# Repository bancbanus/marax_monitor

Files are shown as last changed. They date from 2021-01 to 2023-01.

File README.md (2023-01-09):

# marax_monitor
Shows temperature data and pump activity of Lelit's MaraX (PL62X) espresso machine with an ESP8266 on a 3.2" Nextion display
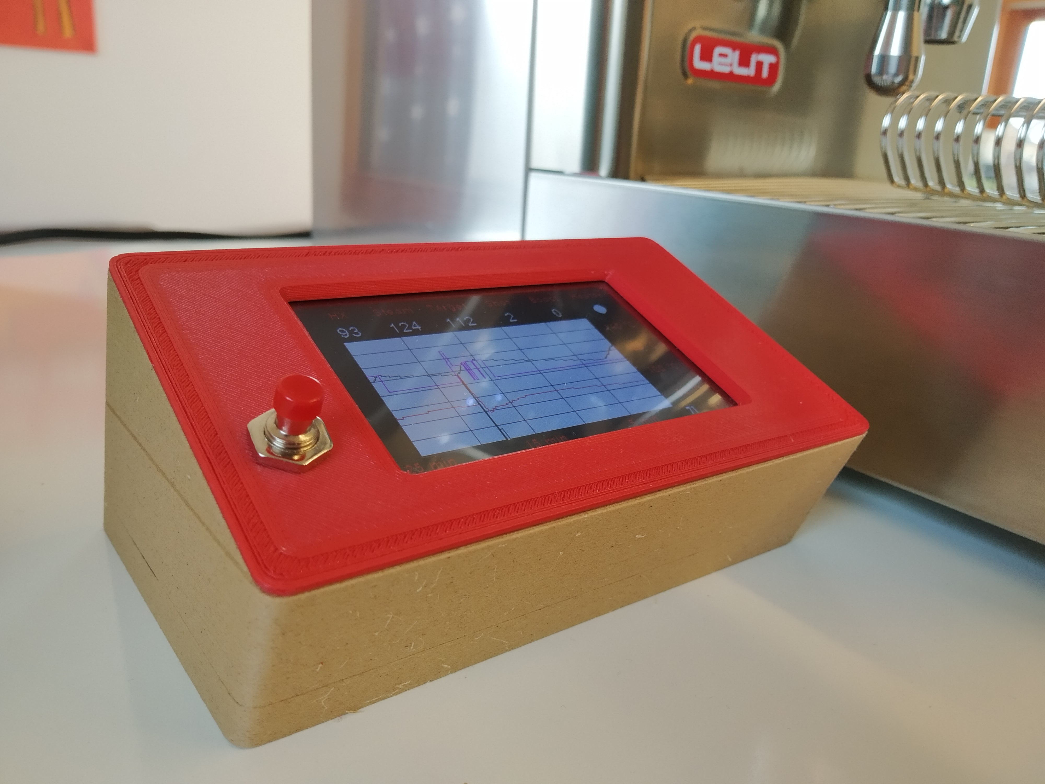
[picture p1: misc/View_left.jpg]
marax_monitor


## Introduction
[Lelit's MaraX (PL62X)](https://marax.lelit.com/) espresso machine is a quite interesting device because of it's "coffee mode", i.e. 
temperature is regulated by measuring the HX temperature instead of the steam temperature. The control unit of the machine provides 
a serial interface which allows us to read all relevant data.

There are already many projects out there which read and display the machine's data, but I want to draw your attention to following 
two projects from where I got a lot of ideas and information (thank you!):

* [calin's excellent post on reddit](https://www.reddit.com/r/espresso/comments/hft5zv/data_visualisation_lelit_marax_mod/)
* [alexrus' great marax_timer project](https://github.com/alexrus/marax_timer)
* [lelit insider's video](https://youtu.be/9NL6yeq7sMM)

Since a Nextion display was laying around in my lab, I created marax_monitor which does the following:

* Display and plot temperatures on a Nextion display
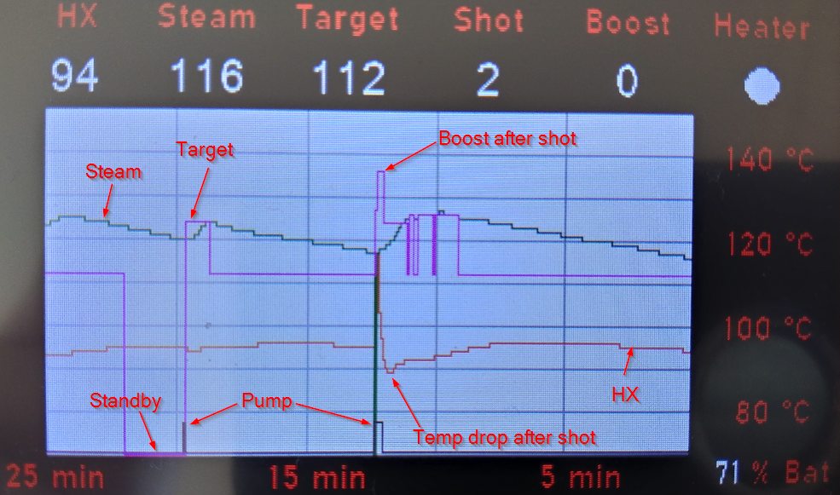
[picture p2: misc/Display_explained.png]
Display

* Display a shot timer (a reed switch has to be attached to the vibration pump)
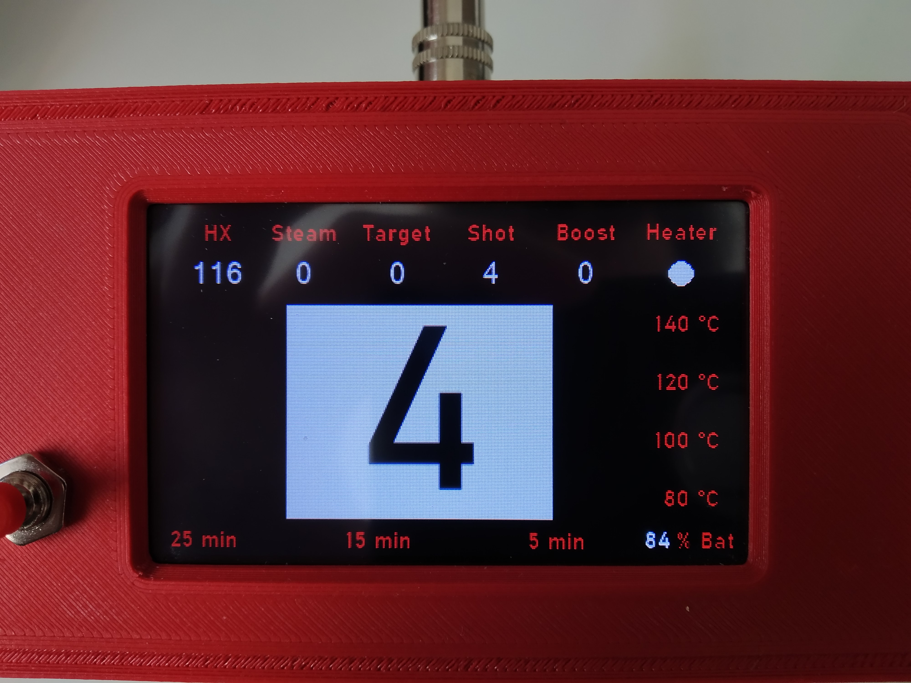
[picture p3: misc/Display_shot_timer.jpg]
Shot timer

* Send data via MQTT to Node-RED and display data on it's dashboard 
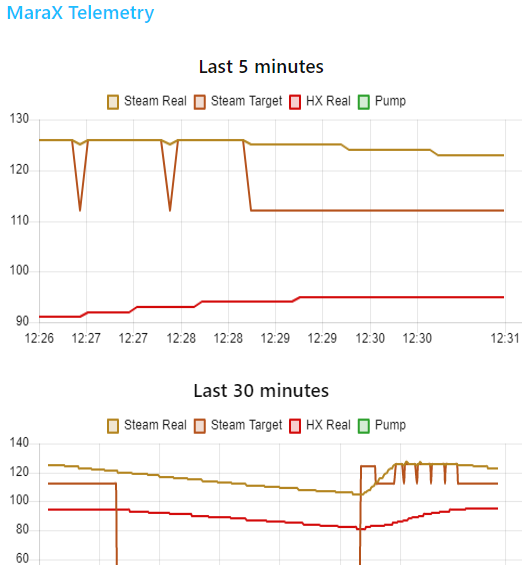
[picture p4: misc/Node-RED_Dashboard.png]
Node-RED dashboard


Additionally I've added ArduinoOTA for being able to upload updates over the network.

The device is powered by an 18650 LiPo battery, that's why I've added a battery shield and a simple circuit for auto power off the monitor
after an hour of inactivity for saving energy. The battery lasts for about one week.

We're using marax_monitor for some weeks now and especially the shot timer is a feature which we do not want miss any more. I also like
to watch the temperature profiles which is not so trivial I've thought of before. 

## BOM

**Note:** I just used components which were available in my lab.

Required:
* ESP8266 development board
* Nextion Display, e.g. [Nextion NX4024T032](https://www.itead.cc/nextion-nx4024t032.html)
* Reed switch, e.g. [MC-38](https://www.aliexpress.com/item/32255861885.html)

Optional (for battery powering):
* Boost converter, e.g. WEMOS battery shield
* Battery, e.g. LiPo 18650

Optional (for auto power off functionality):
* PNP and NPN MOSFETs, resistors, diode

or 

* Soft power latch module, e.g. [Polulu Item #2808](https://www.pololu.com/product/2808)

Case (STL files for 3D printer):
* [3.2" display bezel by Nextion](https://nextion.tech/nextion-editor/#_section4)
* [Case](/hardware/marax_monitor_case.stl)

## Wiring

### MaraX

**Note:** You don't have to remove the complete housing of your espresso machine or empty the boiler. Just turn the machine 90 degrees backwards. 
Control unit and vibration pump can be easily reached by only removing the maintenance hatch on the bottom.

* The three wires of the serial connection (GND, D5 and D6) have to be connected to the GND, RX and TX pins of the MaraX control unit (2nd, 3rd and 
4th pin from the center to the edge). For details please have a look on 
[calin's excellent post on reddit](https://www.reddit.com/r/espresso/comments/hft5zv/data_visualisation_lelit_marax_mod/) or screenshot below

* Reed switch has to be attached to the vibration pump (I used double sided tape). For details please have a look at 
[alexrus' great marax_timer project](https://github.com/alexrus/marax_timer)

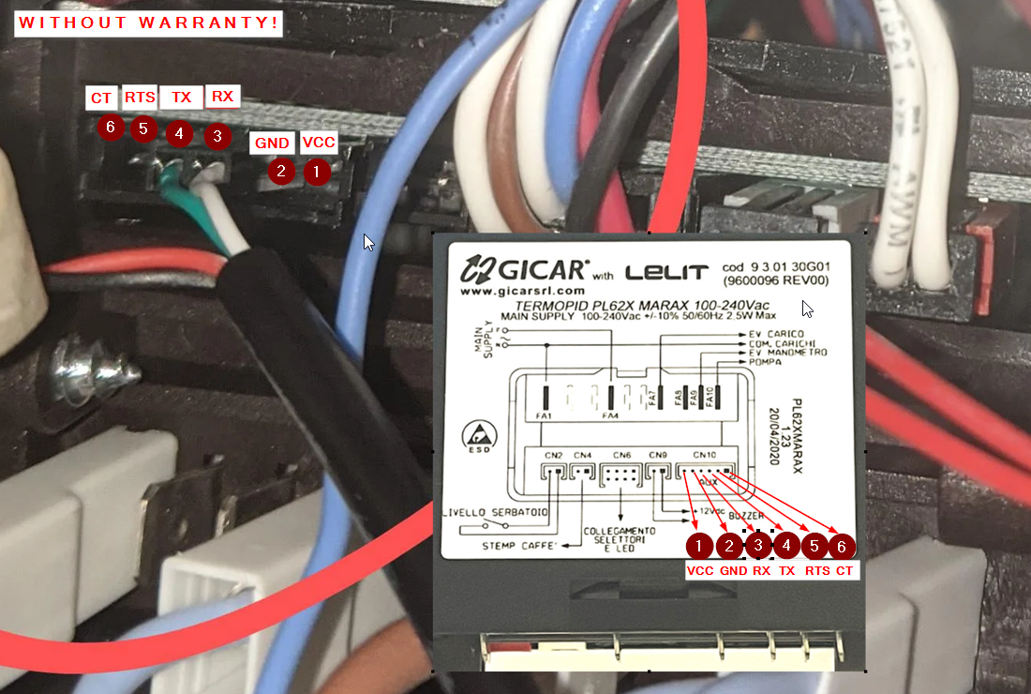
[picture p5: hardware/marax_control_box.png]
MaraX' control box


### Monitor

**Note:** As already mentioned I used components laying around my lab and put them together quick and dirty. 

Device         			                       | ESP8266 
-------------------------------------------| --------
GND pin from MaraX' control unit (2nd pin) | GND
RX pin from MaraX' control unit (3rd pin)  | D6
TX pin from MaraX' control unit (4th pin)  | D5
1st wire from reed switch                  | D3
2nd wire from reed switch                  | GND
RX pin from Nextion display                | D1
TX pin from Nextion display                | D7
GND pin from Nextion display               | GND

Optional (for auto power off and battery status):

Device         			              | ESP8266 
----------------------------------| --------
Gate of NPN MOSFET (power drive)  | D0
Push button (for power on/off)    | D2
Voltage divider for battery status| A0

The circuit for the auto power off functionality I've taken from [Michael Ruppe](https://github.com/michaelruppe/ArduinoSoftTouchPower) 
(thank you!). 

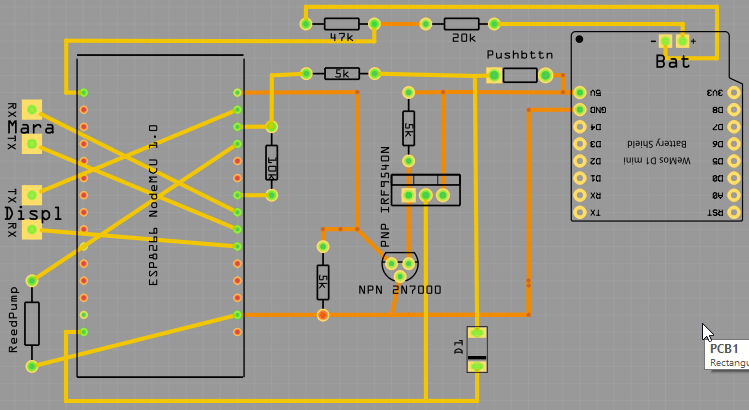
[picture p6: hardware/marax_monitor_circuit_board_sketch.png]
Sketch

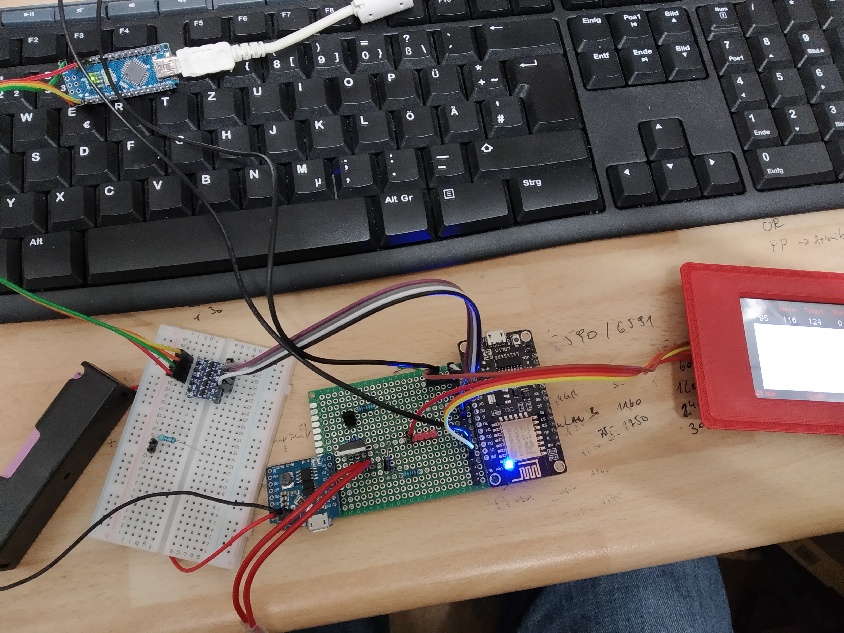
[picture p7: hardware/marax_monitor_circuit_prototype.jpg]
Prototype

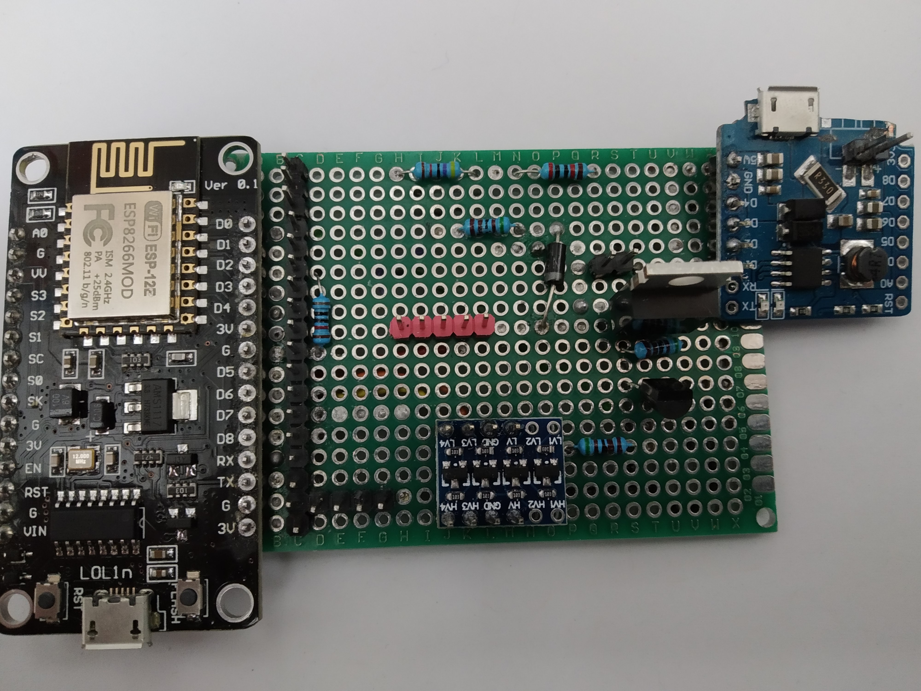
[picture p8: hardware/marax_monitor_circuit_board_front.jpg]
Circuit board front

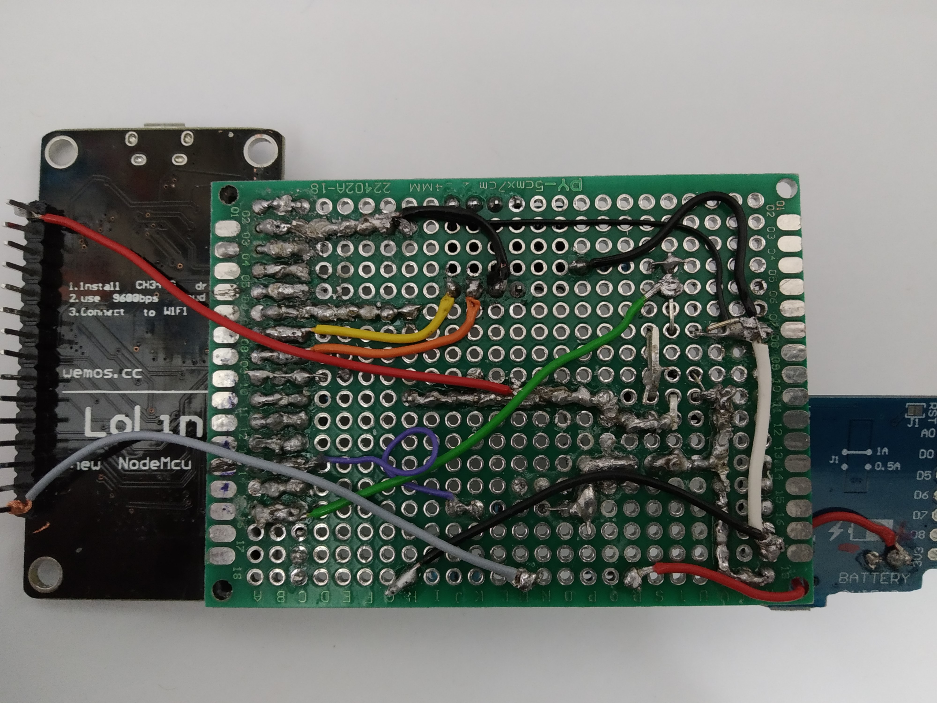
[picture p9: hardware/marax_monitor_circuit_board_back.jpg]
Circuit board back

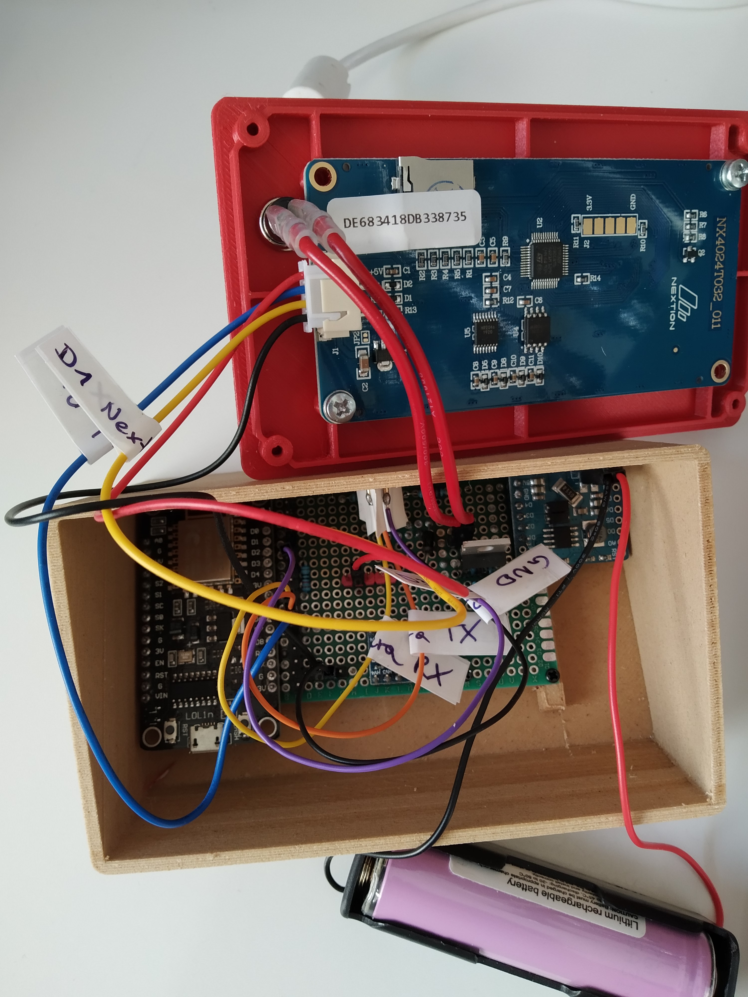
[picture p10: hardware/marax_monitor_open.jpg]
Assembled


## Software

### Used libraries for ESP8266 sketch:
* [arduino-timer](https://github.com/contrem/arduino-timer)
* [PubSubClient](https://pubsubclient.knolleary.net/) MQTT client (optional)
* [ArduinoOTA](https://github.com/jandrassy/ArduinoOTA) (optional)

### Nextion display
Project file for Nextion display (edited on Nextion Editor V1.61.2):
* [marax_monitor_nextion.HMI](/hardware/marax_monitor_nextion.HMI)

### Miscellaneous
* MaraX' control unit sends data via serial interface about twice per second. But marax_monitor reads and displays this data only every 5 seconds 
because that's enough 
* If you've implemented auto power off: the device will be powered off after an hour of inactivity. You can manually power off by long 
pressing the power off button. By short pressing the power off button the counter for auto power off will be reset.

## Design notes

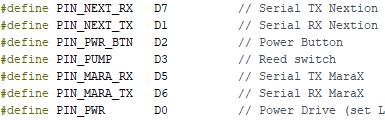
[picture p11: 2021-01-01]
hardware/marax_monitor_pinout.png

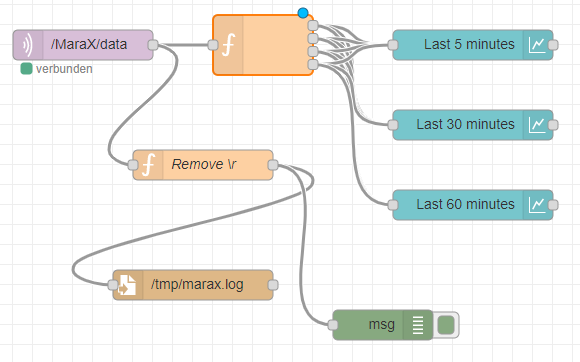
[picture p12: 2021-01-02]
misc/Node-RED_flow.png

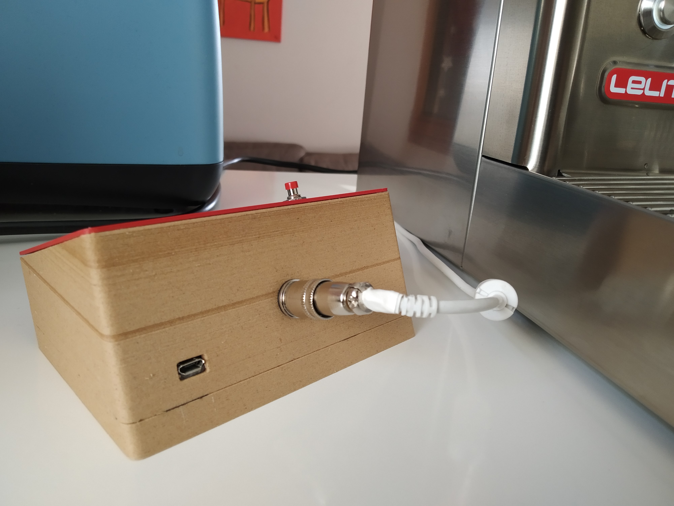
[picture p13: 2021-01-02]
misc/View_back.jpg

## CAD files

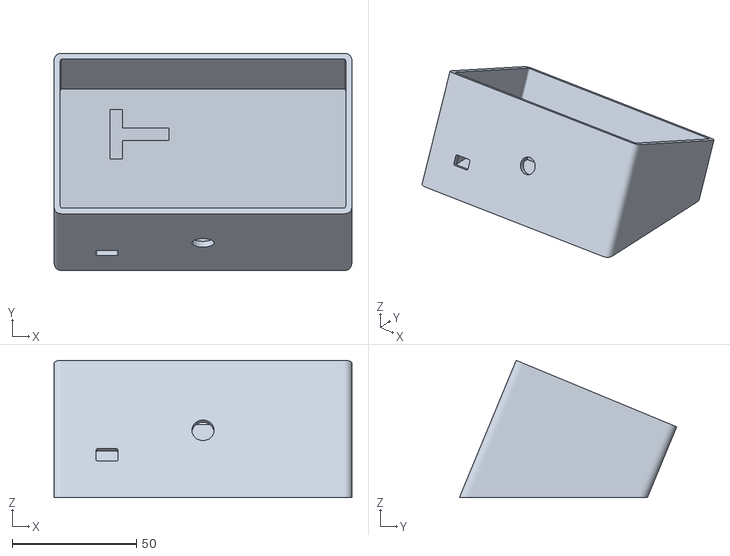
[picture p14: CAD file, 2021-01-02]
hardware/marax_monitor_case.stl
120.0 x 87.6 x 55.3

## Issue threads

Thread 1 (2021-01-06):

Power off button of monitor does not work if marax is switched off

bancbanus, 2021-01-06:
It does only switch off when you press the button more than five seconds

bancbanus, 2021-02-07:
Fixed

Closed 2021-02-07.

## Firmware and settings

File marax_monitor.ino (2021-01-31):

//NodeMCU 1.0 (ESP-12E)
#define PIN_NEXT_RX   D7          // Serial TX Nextion Display
#define PIN_NEXT_TX   D1          // Serial RX Nextion Display
#define PIN_PWR_BTN   D2          // Power Button
#define PIN_PUMP      D3          // Reed switch                                                                                                             
#define PIN_MARA_RX   D5          // Serial TX MaraX
#define PIN_MARA_TX   D6          // Serial RX MaraX
#define PIN_PWR       D0          // Power Drive (set LOW to power off)
#define PWR_OFF_DELAY 600         // Hold button 0.6 sec to power off
#define PWR_OFF_AUTO  3600000     // Auto Power Off after 1 hour

#include "config.h"
#include <ESP8266WiFi.h>
#include <PubSubClient.h>
#include <arduino-timer.h>
#include <SoftwareSerial.h>
#include <ArduinoOTA.h>
#include <ESP_EEPROM.h>

WiFiClient espClient;
PubSubClient mqttClient(espClient);
SoftwareSerial maraSerial(PIN_MARA_RX, PIN_MARA_TX);
SoftwareSerial nextSerial(PIN_NEXT_RX, PIN_NEXT_TX);
auto timer = timer_create_default();

byte timerSeconds = 0;
bool timerStarted = false;
long timerStartMillis = 0;
long timerStopMillis = 0;
long displayUpdateMillis = 0;
long autoPowerOffMillis = 0;
long isPoweredOff = 0;

const byte numChars = 32;
char receivedChars[numChars];

boolean newData = false;

//Data sent by MaraX, e.g. C1.19,116,124,095,0560,0
enum { mode_version, steam_temp, steam_target, hx_temp, boost, heater, pump };

void setup() {

  pinMode(PIN_PWR, OUTPUT);
  digitalWrite(PIN_PWR, HIGH);

  pinMode(LED_BUILTIN, OUTPUT);
  digitalWrite(LED_BUILTIN, HIGH);  //disable to save energy

  pinMode(PIN_PWR_BTN, INPUT);
  pinMode(PIN_PUMP, INPUT_PULLUP);

  Serial.begin(9600);
  maraSerial.begin(9600);
  nextSerial.begin(9600);

  delay(100);

  //writeEEPROM(0);

  timer.every(200, shotTimer);
  timer.every(10000, getBattery);
  timer.every(100000, autoPowerOff);

  NexVisible( "nCounter", false );
  NexVisible( "tStats", false );
  getBattery;
  autoPowerOffMillis = millis();

  setup_wifi();

  if ( WiFi.status() == WL_CONNECTED) {

    ArduinoOTA.onStart([]() {
      String type;
      if (ArduinoOTA.getCommand() == U_FLASH) {
        type = "sketch";
      } else { // U_FS
        type = "filesystem";
      }

      // NOTE: if updating FS this would be the place to unmount FS using FS.end()
      Serial.println("Start updating " + type);
    });
    ArduinoOTA.onEnd([]() {
      Serial.println("\nEnd");
    });
    ArduinoOTA.onProgress([](unsigned int progress, unsigned int total) {
      Serial.printf("Progress: %u%%\r", (progress / (total / 100)));
    });
    ArduinoOTA.onError([](ota_error_t error) {
      Serial.printf("Error[%u]: ", error);
      if (error == OTA_AUTH_ERROR) {
        Serial.println("Auth Failed");
      } else if (error == OTA_BEGIN_ERROR) {
        Serial.println("Begin Failed");
      } else if (error == OTA_CONNECT_ERROR) {
        Serial.println("Connect Failed");
      } else if (error == OTA_RECEIVE_ERROR) {
        Serial.println("Receive Failed");
      } else if (error == OTA_END_ERROR) {
        Serial.println("End Failed");
      }
    });
    ArduinoOTA.begin();

    mqttClient.setServer(MQTT_BROKER, MQTT_PORT);
    if (!mqttClient.connected()) {
      mqttReconnect();
    }
  }
}

void loop() {

  timer.tick();

  detectPump();
  detectTouchscreen();
  detectPowerbutton();

  receiveData();

  if (newData == true) { 
    newData = false; 
    if (millis() - displayUpdateMillis > 5000) { 
      parseData();
      displayUpdateMillis = millis();
    }
  } else {
    if ( millis() - displayUpdateMillis > 5500 ) {
      //machine was switched off
      strncpy(receivedChars, "0,0,0,0,0,0,0", numChars);
      parseData();
      displayUpdateMillis = millis();
    }
  } 

  if ( WiFi.status() == WL_CONNECTED) {
    ArduinoOTA.handle();
    if (mqttClient.connected()) {
      mqttClient.loop();
    }
  }
  
}

void receiveData() {
  static boolean recvInProgress = false;
  static byte ndx = 0;
  char startMarker1 = 'C';  //Coffee mode
  char startMarker2 = 'V';  //Vapor mode
  char endMarker = '\n';
  char rc;

  while (maraSerial.available() > 0 && newData == false) {
    rc = maraSerial.read();
    delay(5);

    if (recvInProgress == true) {
      if (rc != endMarker) {
        receivedChars[ndx] = rc;
        ndx++;
        if (ndx >= numChars) {
          ndx = numChars - 1;
        }
      } else {
        //add pump status
        ndx--;
        receivedChars[ndx] = ',';
        ndx++;
        if (timerStarted) {
          receivedChars[ndx] = '1';
        } else {
          receivedChars[ndx] = '0';
        }
        ndx++;
        receivedChars[ndx] = '\0';
        recvInProgress = false;
        ndx = 0;
        newData = true;
        Serial.println( receivedChars );
      }
    } else if (rc == startMarker1 || rc == startMarker2) {
      receivedChars[0] = rc;
      ndx++;
      recvInProgress = true;
    }
  }
}

void parseData() {

  char copy[numChars];
  char sep[] = ",";
  char* token;
  int var;
  int input[5];
  int i = 0;
  byte data[7];

  strcpy(copy, receivedChars);

  token = strtok (copy, sep);
  while (token != NULL)
  {
    sscanf (token, "%d", &var);
    data[i++] = var;
    token = strtok (NULL, sep);
  }

  if ( WiFi.status() == WL_CONNECTED) {
    mqttClient.publish(MQTT_TOPIC, receivedChars);
  }

  // y = 2x - 140 (for 3.2" display)
  NexWave( 1, 0, 2 * data[hx_temp] - 140 );
  NexWave( 1, 1, 2 * data[steam_temp] - 140 );
  NexWave( 1, 2, 2 * data[steam_target] - 140 );

  if (timerStarted) {
    NexWave( 1, 3, 15 );
  } else {
    NexWave( 1, 3, 1 );
  }

  NexNumber( "nHX", data[hx_temp] );
  NexNumber( "nSteam", data[steam_temp] );
  NexNumber( "nTarget", data[steam_target] );
  NexNumber( "nShot", timerSeconds );

  NexNumber( "nBoost", data[boost] );

  if (data[heater]) {
    NexCircle("RED");
  } else {
    NexCircle("WHITE");
  }
}

void detectPump() {
  if (!timerStarted && !digitalRead(PIN_PUMP)) {
    timerStartMillis = millis();
    timerStarted = true;

    NexVisible( "sWave", false );
    NexVisible( "tStats", false );
    NexVisible( "nCounter", true );
    Serial.println("Start pump");
  }
  if (timerStarted && digitalRead(PIN_PUMP)) {
    if (timerStopMillis == 0) {
      timerStopMillis = millis();
    }
    if (millis() - timerStopMillis > 500) {
      timerStarted = false;
      timerStopMillis = 0;

      NexVisible( "nCounter", false );
      NexVisible( "sWave", true );

      if( timerSeconds > 15 ) {
        int shotCounter = readEEPROM( );
        writeEEPROM( ++shotCounter );
      }
      Serial.println("Stop pump");
    }
  } else {
    timerStopMillis = 0;
  }
}

void detectPowerbutton() {
  long unsigned int start;

  if (digitalRead(PIN_PWR_BTN)) {
    start = millis();
    while (digitalRead(PIN_PWR_BTN)) {
      Serial.println("Button pressed");
      if (millis() > (start + PWR_OFF_DELAY)) {
        Serial.println("Power off");
        while (digitalRead(PIN_PWR_BTN)) {}
        delay(150);
        digitalWrite(PIN_PWR, LOW);
      }
      if (millis() > (start + 100)) {
        //reset auto power counter off when short push
        autoPowerOffMillis = millis();
      }
    }
  }
}

void detectTouchscreen() {

  char rc;
  int count;
  int a5count;
  boolean gotData = false;
  char textStats[20];

  while (nextSerial.available()) {
    rc = nextSerial.read();
    Serial.printf("%02x ", rc);
    delay(3);
    count++;
    if (rc == 0xa5) {
      a5count++;
    }
    if (rc != 0xa5 && a5count > 2 && gotData == false) {
      gotData = true;
      displayUpdateMillis = millis();
      if (rc == 0x01) {
        Serial.print("Statistik");
        //itoa(readEEPROM( ), textStats, 10);
        sprintf(textStats, "%i shots", readEEPROM( ) );
        
        //textStats = textStats && " shots";
        NexText( "tStats", textStats );
        NexVisible( "tStats", true );
      } else if (rc == 0x00) {
        Serial.print("Keine Statistik");
        NexVisible( "tStats", false );
      }
    }
  }
}

boolean autoPowerOff(void *) {
  if (millis() - autoPowerOffMillis > PWR_OFF_AUTO) {
    digitalWrite(PIN_PWR, LOW);
  }
  return true;
}

boolean shotTimer(void *) {
  if (timerStarted) {
    timerSeconds = round((millis() - timerStartMillis) / 1000.0 );
    NexNumber( "nCounter", timerSeconds );
    NexNumber( "nShot", timerSeconds );
  }
  return true;
}

boolean getBattery(void *) {
  unsigned int average = 0;
  for (int i = 0; i < 10; i++)  {
    average += analogRead(A0);
  }
  average = average / 10;

  NexNumber( "nBat", (int)round( average * 100.0 / 244 - 65000.0 / 244 ) );
  return true;
}

void NexWave( byte id, byte ch, int val) {

  (val < 0) && ( val = 0 );

  String cmd = "add ";
  cmd += id;
  cmd += ",";
  cmd += ch;
  cmd += ",";
  cmd += val;
  nextSerial.print(cmd);
  nextSerial.write(0xff);
  nextSerial.write(0xff);
  nextSerial.write(0xff);
}

void NexNumber( char* id, byte number) {
  String cmd = id;
  char val[10] = {0};

  utoa(number, val, 10);

  cmd += ".val=";
  cmd += val;
  nextSerial.print(cmd);
  nextSerial.write(0xff);
  nextSerial.write(0xff);
  nextSerial.write(0xff);
}

void NexText( char* id, char* text ) {
  String cmd = id;

  cmd += ".txt=\"";
  cmd += text;
  cmd += "\"";
  Serial.println(cmd);
  nextSerial.print(cmd);
  nextSerial.write(0xff);
  nextSerial.write(0xff);
  nextSerial.write(0xff);
}

void NexVisible( char* id, bool visibility ) {

  String cmd = "vis ";
  cmd += id;
  cmd += ",";

  if (visibility) {
    cmd += "1";
  } else {
    cmd += "0";
  }

  nextSerial.print(cmd);
  nextSerial.write(0xff);
  nextSerial.write(0xff);
  nextSerial.write(0xff);
}

void NexCircle( char* color ) {

  String cmd = "cirs 359,44,8,";
  cmd += color;

  nextSerial.print(cmd);
  nextSerial.write(0xff);
  nextSerial.write(0xff);
  nextSerial.write(0xff);
}

void setup_wifi() {
  short timeout = 0;
  delay(10);
  Serial.println();

  Serial.print("Connecting to ");
  Serial.println(WIFI_SSID);

  WiFi.begin(WIFI_SSID, WIFI_PWD);

  while (WiFi.status() != WL_CONNECTED) {
    timeout++;
    if (timeout > 10) {
      Serial.println("Can't connect to WIFI");
      return;
    }
    delay(500);
    Serial.print(".");
  }

  Serial.println("WiFi connected");
  Serial.println("IP address: ");
  Serial.println(WiFi.localIP());
}

void mqttReconnect() {
  int tries = 0;

  while (!mqttClient.connected()) {
    Serial.println("Reconnecting MQTT...");
    if (tries > 3) {
      break;
    }
    if (!mqttClient.connect("mqttClient")) {
      Serial.print("failed, rc=");
      Serial.print(mqttClient.state());
      Serial.println(" retrying in 1 seconds");
      tries++;
      delay(1000);
    }
  }
  if (mqttClient.connected()) {
    Serial.println("MQTT Connected...");
  } else {
    Serial.println("MQTT Connection failed...");
  }
}

int readEEPROM( ) {
  int savedValue;
  EEPROM.begin(16);
  EEPROM.get(0, savedValue);
  return savedValue;
}

void writeEEPROM( int value ) {
  EEPROM.begin(16);
  EEPROM.put(0, value);
  boolean ok1 = EEPROM.commit();
  Serial.println((ok1) ? "First commit OK" : "Commit failed");
}

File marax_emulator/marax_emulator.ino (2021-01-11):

char *output[] = {
"0,0,0,0,0,0",                //machine is OFF
"0,0,0,0,0,0",
"0,0,0,0,0,0",
"0,0,0,0,0,0",
"0,0,0,0,0,0",
"0,0,0,0,0,0",
"0,0,0,0,0,0",
"C1.23,050,140,043,1191,1",   //machine is switched ON
"C1.23,050,140,042,1186,1",
"C1.23,051,140,041,1181,1",
"C1.23,051,140,040,1176,1",
"C1.23,052,140,040,1170,1",
"C1.23,054,140,039,1165,1",
"C1.23,055,140,039,1160,1",
"C1.23,057,140,039,1155,1",
"C1.23,058,140,038,1150,1",
"C1.23,060,140,038,1144,1",
"C1.23,061,140,038,1139,1",
"C1.23,063,140,038,1134,1",
"C1.23,064,140,038,1129,1",
"C1.23,066,140,038,1124,1",
"C1.23,067,140,038,1118,1",
"C1.23,069,140,038,1113,1",
"C1.23,070,140,038,1108,1",
"C1.23,072,140,038,1103,1",
"C1.23,074,140,038,1098,1",
"C1.23,075,140,038,1092,0",
"C1.23,077,140,038,1087,1",
"C1.23,078,140,038,1082,1",
"C1.23,079,140,039,1077,0",
"C1.23,080,140,039,1072,0",
"C1.23,081,140,039,1066,1",
"C1.23,082,140,039,1061,1",
"C1.23,085,140,039,1056,0",
"C1.23,085,140,039,1051,1",
"C1.23,085,140,040,1046,1",
"C1.23,086,140,040,1040,0",
"C1.23,087,140,040,1035,1",
"C1.23,088,140,040,1030,0",
"C1.23,089,140,041,1025,0",
"C1.23,089,140,041,1020,1",
"C1.23,090,140,041,1014,0",
"C1.23,091,140,041,1009,1",
"C1.23,091,140,042,1004,0",
"C1.23,091,140,042,0999,1",
"C1.23,091,140,042,0994,1",
"C1.23,092,140,043,0988,0",
"C1.23,093,140,043,0983,1",
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
"C1.23,116,000,094,0000,0", //machines goes into standby
"C1.23,116,000,094,0000,0",
"C1.23,116,000,094,0000,0",
"C1.23,116,000,094,0000,0",
"C1.23,116,000,094,0000,0",
"C1.23,115,000,094,0000,0",
"C1.23,115,000,094,0000,0",
"C1.23,115,000,094,0000,0",
"C1.23,115,000,094,0000,0",
"C1.23,115,000,094,0000,0",
"C1.23,115,000,094,0000,0",
"C1.23,115,000,094,0000,0",
"C1.23,115,000,094,0000,0",
"C1.23,115,000,094,0000,0",
"C1.23,115,000,094,0000,0",
"C1.23,115,000,094,0000,0",
"C1.23,114,000,094,0000,0",
};

static int i = 0;

void setup() {
  Serial.begin(9600);
}

void loop() {

  int x;

  //Send for 5 secs the same data
  for (x = 0; x < 10; x++ ) {
    Serial.println( output[i] );      
    delay(500);
  }     
  if (i == 687) {
    i = 0;
  } else {
    i++;
  }
  
}

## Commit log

2021-01-02 Added files for documentation
    [marax_monitor.fzz, marax_monitor_case.stl, marax_monitor_circuit_board.fzz]
2021-01-31 added shot counter
    - shots longer than 15 secs are counted and saved to EEPROM
    - bugfixes:
    + power off button when machine is switched off
    + timeout when mqtt is not available
    [marax_monitor.ino]
